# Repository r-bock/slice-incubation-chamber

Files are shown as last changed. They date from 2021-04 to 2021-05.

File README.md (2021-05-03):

# Slice incubation chamber
These files are [OpenSCAD](http://openscad.org/) files, which create a slice incubation chamber that fits into a 250 ml glass beaker. The file is the source for both, the chamber and the grid/mesh, though there are two separate STL files for them. The small holder fits the [gas dispersion tubes](https://www.fishersci.com/shop/products/pyrex-gas-dispersion-tubes-with-fritted-cylinders-2/11138B) for continued oxygenation of the imersion solution.

The chamber went through multiple iterations since 2017 and the latest is version *3 E*, 
which shows small modifications to the previous version based on specific preferences. The chambers are in constant use in a laboratory setting. 

The version *3 D* has the following design: 

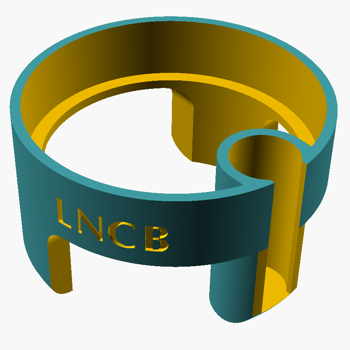
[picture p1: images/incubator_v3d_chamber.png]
incubation chamber
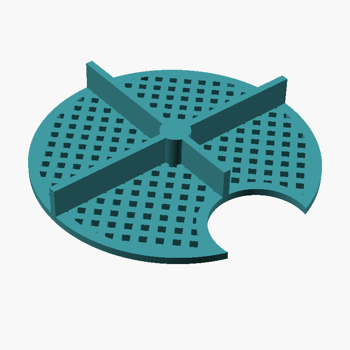
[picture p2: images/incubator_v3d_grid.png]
slice incubation grid
   

## Materials

The print material for the chamber is [PETG](https://www.acmeplastics.com/what-is-petg), which is considered food-safe. PETG worked well in the laboratory setting since 2017. *PLA* might also work, but I haven't tried it exhaustively.

The chamber needs to be submerged within a saline solution for long times, so the print material must be biological inert (i.e. not leaching any trace amounts) and create a solid surface to prevent any solution leaking into the inner structure (which, depending on the print, is often not solid but a 20-30% infill).

## Stuff

 <br />
These files are copyrighted 2021 by R. Bock and are licensed under a [Creative Commons Attribution-NonCommercial-ShareAlike 4.0 International License](http://creativecommons.org/licenses/by-nc-sa/4.0/).

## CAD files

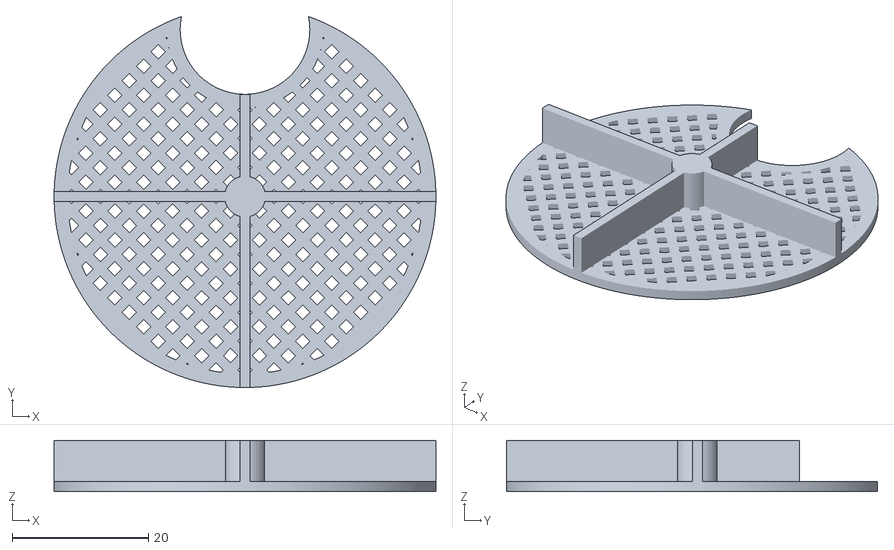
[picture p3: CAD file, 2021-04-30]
incubator_v3d_grid.stl
56.0 x 54.4 x 7.50

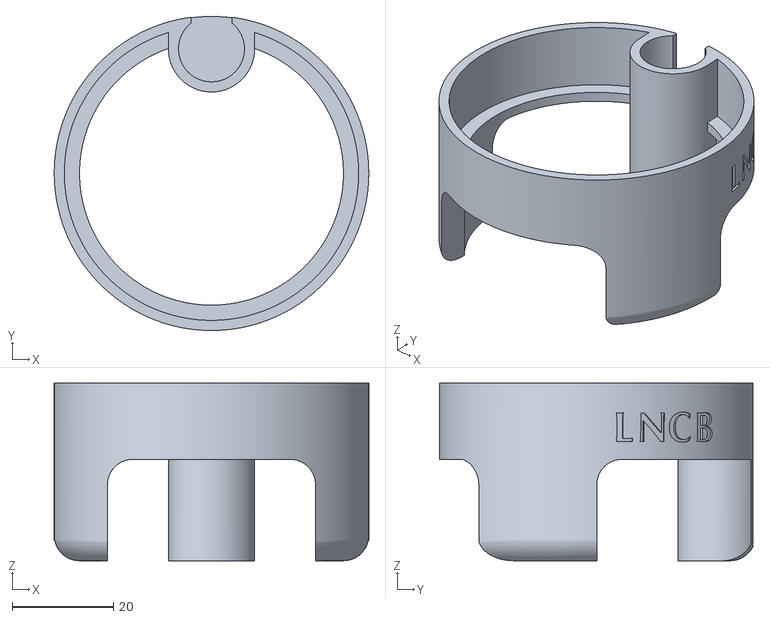
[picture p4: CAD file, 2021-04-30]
incubator_v3d_chamber.stl
62.0 x 61.9 x 35.0

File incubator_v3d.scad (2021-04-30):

// main incubation chamber
$fs=0.5;
$fa=0.5;

use <text_on.scad>;

// all measurements are given in mm!

//font = "Monaco:style=Regular";
font="Optima:style=Bold";
letterHeight=1.5;
letterSize=6;
spacing=1.1;
msg = "LNCB";
vMsg = "v3D";

beakerD = 62; 			// beaker diameter
bradius = 6.5;
bwall = 2;
bledge = 4.5;
bBottom = 3;
cwall = 2;
cheight = 15;
ledgeWidth = 3;
legheight = 20;

meshHeight = 1.5;

supportArcR = 5;

cradius = beakerD/2;
legWidth = (cradius * 2) * (1 / 2);


// main arrangement of chamber and meshes
translate([0, 0, legheight]) chamber();
// translate([2 * beakerD + beakerD/4, 0, 0]) chamber();
// translate([2 * beakerD + beakerD/4, beakerD + beakerD/8, 0]) rotate([0, 0, 180]) chamber();


// for (t = [ [-beakerD/2-8, beakerD-5, -legheight],
//           [beakerD/4+5, beakerD-5, -legheight],
//           [beakerD + 5, 0, -legheight],
//           [-(beakerD + 5), 0, -legheight], 
//           [1.3 * beakerD, beakerD-5, -legheight] ])
//     translate(t) grid(barThick, bDist, fBorder, tol, 1.5);

* grid(barThick, bDist, fBorder, tol, 1.5);

// modules
module chamber() {
	difference() {
	// chamber with bubble holder
	union() {
		// main chamber
		difference() {
			color("aqua")
				translate([0,0,-legheight]) cylinder(r=cradius,h=cheight + legheight);
			translate([0,0,2]) cylinder(r=cradius-cwall, h=cheight);
			translate([0,0,-legheight - 1]) cylinder(r=cradius-cwall-ledgeWidth, h=cheight + legheight);
			translate([0,cradius-bradius,-legheight]) cylinder(r=bradius, h=cheight + legheight + 5);

			// creating a block to crated the legs with nice rounds
			translate([0,cradius-legWidth+supportArcR,-legheight-(supportArcR/2)+0.5]) {
				minkowski() {
					rotate([0,90,0]) cylinder(r=supportArcR,h=cradius + 2, center=true);
					translate([-cradius/2,0,0]) 
						cube([cradius,legWidth-supportArcR,legheight - supportArcR + 2]);
				}
			}
	
			// separating arc
			translate([-legWidth/2,-beakerD/2+((cwall+ledgeWidth) * 3),-legWidth-1+supportArcR])
				rotate([90,0,0])
					linear_extrude(height=(cwall+ledgeWidth+5) * 2)
						minkowski() {
							square([legWidth, legheight + 2]);
							circle(r=supportArcR);
						}
			
			text_on_cylinder(msg, r=cradius, h=13, font=font, size=letterSize, extrusion_height=letterHeight, eastwest=122, spacing=spacing);
			text_on_cylinder(vMsg, r=cradius, h=13, font=font, size=letterSize, extrusion_height=letterHeight, eastwest=-120, spacing=spacing);
		}

		difference() {
			union() {
				// now for the bubble holder
				translate([0,cradius-bradius,-legheight])	{
	    				difference() {
	        				cylinder(r=bradius + bwall, h=legheight+cheight);
						translate([0,0,bBottom])
//							difference() {
								cylinder(r=bradius, h=cheight+legheight+2);
//								rotate([-10,0,0])
//									translate([-bradius-1, -bradius-1, -(bradius/2) * 0.65])
//										cube([(2 * bradius) + 2, (2 * bradius) + 2, bradius/2]);
//							}

//    		    				translate([0,0,bBottom])
//     	   					cylinder(r=bradius, h=legheight+cheight);
    					}
				}

				// bubble connector
				translate([-bradius-bwall,cradius-bradius,0]) {
					difference() {
						cube([(bradius+bwall)*2,bradius+bwall,cheight]);
						translate([bradius+bwall,0,-1])
							cylinder(r=bradius, h=cheight+2);
						translate([bradius+bwall,-beakerD/2+bradius+bwall-0.5, -1]) {
							difference() {
								cylinder(d=beakerD+5, h=cheight+2);
								cylinder(d=beakerD, h=cheight+2);	
							}
						}
					}
				}
			}

			translate([0,0,-legheight-1]) {
				linear_extrude(height=cheight+legheight+2) {
					difference() {
						offset(r=3)
							circle(r=cradius); 
						circle(r=cradius);
						
					}
				}
			}			
		}
	}

	translate([0, cradius, bBottom-bwall])
		cube([bwall * 4, bwall * 1.5, cheight+legheight + 0.95], center=true);
	
	
	// slant the legs
	scale([1,1.01,1]) {
		translate([0,-bradius-bwall/2,-legheight+supportArcR]) {
			difference() {
				translate([0,bradius+(bwall/2),-supportArcR-1])
					linear_extrude(height=supportArcR, convexity=10)
						circle(d=beakerD);

				difference() {
					translate([0,bradius+(bwall/2),0])
						rotate_extrude(convexity=10)
							translate([beakerD/2-supportArcR,0,0]) circle(r=supportArcR);

					translate([0,bradius+(bwall/2),0])
						linear_extrude(height=supportArcR, convexity=10) circle(d=beakerD);
				}

				translate([0,bradius+(bwall/2),-supportArcR-2])
					linear_extrude(height=2*supportArcR, convexity=10)
						circle(d=beakerD-(supportArcR*2));

			}
		}
	}
	}
}

gridR = cradius-cwall-0.5;
barThick = 1.5;		// thickness of the bar in mm
bDist = 1.5;			// distance between bars in mm
tol = 1;			// tolerance, i.e. how far away from the border
fBorder = 2;		// frameborder in mm


module grid(barThick, barDist, frameBorder, tolerance, height) {
	barThick = barThick < 1 ? 1 : barThick;
	barDist = barDist < 1 ? 1 : barDist;
	frameBorder = frameBorder < 1 ? 1 : frameBorder;
	tolerance = tolerance <= 0 ? 1 : tolerance;
	height = height <= 0 ? 1.5 : height;

	linear_extrude(height=height) {
		union() {
			gridInsertFrame(frameBorder, tolerance);
			gridStructure(barThick, barDist, frameBorder, tolerance);
		}
	}
	linear_extrude(height=cheight/2, convexity=10) {
		circle(r=(barThick * 2));
		translate([-barThick/2,-gridR+(tolerance/2),0])
			square([barThick,2 * (gridR - (tolerance/2) - bradius)]);
		translate([gridR-(tolerance/2),-barThick/2,0])
			rotate([0,0,90])
				square([barThick,2 * (gridR - (tolerance/2))]);
	}
}


module gridStructure(barThick, barDist, frameBorder, tolerance) {
	barThick = barThick < 1 ? 1 : barThick;
	barDist = barDist < 1 ? 1 : barDist;
	frameBorder = frameBorder < 1 ? 1 : frameBorder;
	tolerance = tolerance <= 0 ? 1 : tolerance;
	
	numBars = ceil((gridR * 2) / (barThick + barDist));
	
	difference() {
		union() { 
			rotate([0,0,45]) {
				for (n = [0:numBars]) {
					translate([(n * (barThick + barDist)) - gridR, 0, 0])
						square([barThick,2 * gridR], center=true);
				}
			}	
			rotate([0,0,-45]) {
				for (n = [0:numBars]) {
					translate([gridR - (n * (barThick + barDist)), 0, 0])
						square([barThick,2 * gridR], center=true);
				}
			}
		}
		
		difference() {
			rotate([0,0,45]) square((2*gridR) + 2 * (barThick + barDist), center=true);
			difference() {
				circle(r=(beakerD/2) - cwall-tolerance);
				translate([0, beakerD/2 - bradius, 0]) circle(r=bradius+bwall+cwall+tolerance);
				offset(r=1)
					translate([-bradius-bwall,cradius-cwall-bradius,0])
						square([(bradius+bwall)*2, bradius+bwall]);
				
			}
		}
	}
}


module gridInsertFrame(frameBorder, tolerance) {
	frameBorder = frameBorder < 1 ? 1 : frameBorder;
	tolerance = tolerance <= 0 ? 1 : tolerance;

	difference() {
		circle(r=(beakerD/2)-cwall-tolerance);
		offset(r=-2)
			circle(r=(beakerD/2)-cwall-tolerance);
		translate([0, cradius-cwall-bradius/2, 0])
			circle(r=bradius+bwall+tolerance+1);
	}
	difference() {
		offset(r=3) {
			translate([0,cradius-bradius,0])
				circle(r=bradius+bwall);
		}
		offset(r=1) {
			translate([-bradius,cradius-cwall-bradius,0])
				square([(bradius)*2, bradius+bwall]);
			translate([0,cradius-bradius,0])
				circle(r=bradius+bwall);
		}
		difference() {
			circle(r=(beakerD/2)+cwall+bwall+5);
			circle(r=(beakerD/2)-cwall-1);
		}
	}
}

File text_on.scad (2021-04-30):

/*  text on ....
   This is a rework of version 3 of write.scad to use the new OpenSCAD internal text() primitive.
   All credit to Harlan Martin (harlan@sutlog.com) for his great effort on the original.
   Great thanks to t-paul (and the OpenSCAD dev team) on adding the new text() primitive.
*/


/*
The arguments to be provided for each function are explictly in the modules.

All modules take close to all the arguments to text() [Not all features are supported in all text_on_object() modules though -- try them out warnings will be given if it is not supported]

text() params:
t
size
spacing
font
direction -- ltr, ttb, btt or rtl
language
script
halign -- left, right or center
valign -- baseline, bottom, top or center

All modules also take the additional arguments:
extrusion_height = depth of the letter, i.e. how far it sits proud
rotate
center //center the text at the location it is being written (NOT that the object is centered)

ALL faux-objects that the text is applied to have center=true
TODO: object_center=true/false (already done for cylinder)

The above arguemnts can be seen in text_extrude() as all modules call that module evetually (often multiple times).

locn_vector -- Where the faux-object has been translated to. TODO: Rename object to translate_vector?

Additional arguments for text_on_cube():

Additional arguments for text_on_cylinder():

Additional arguments for text_on_circle():

Additional arguments for text_on_sphere():


*/

// These control the default values for text_extrude(), text_on_sphere(), text_on_cube(), text_on_cylinder(), text_on_circle()
// if the arguments are not included in the call to the module.

// Defaults
// Defaults for all modules
default_t="text_on";
default_size = 4; //TODO - Can we make this 10?? To match internal size? There is an underlying value in text() -- This masks that.
default_font = "Liberation Mono";
default_spacing = 1; //Spacing between characters. There is an underlying value in text() -- This masks that. We try and match it here.
default_rotate  = 0; // text rotation (clockwise)
default_center  = true; //Text-centering
default_scale = [1,1,1];
default_extrusion_height = 2; //mm letter extrusion height

//Defaults for Cube
default_cube_face        = "front";	 // default face (top,bottom,left,right,back,front)
default_sphere_rounded   = false;	 //default for rounded letters on text_on_sphere
default_cube_updown = 0; //mm up (-down) from center on face of cube
default_cube_rightleft = 0;		 //mm right(-left) from center on face of cube

//Defaults for Sphere
default_sphere_northsouth= 0;
default_sphere_eastwest  = 0;
default_sphere_spin      = 0; //TODO:Different to rotate? or up/down. Better name?

//Defaults for Cylinder (including circle as it is on top/bottom)
default_circle_middle    = 0;      //(mm toward middle of circle)
default_circle_ccw       = false;  //write on top or bottom in a ccw direction
default_circle_eastwest  = 0;
default_cylinder_face    = "side";
default_cylinder_updown  = 0;

//Internal values - don't play with these :)
//This is much more accurate than the PI constant internal to Openscad.
internal_pi=3.1415926535897932384626433832795028841971693993751058209;
internal_pi2=internal_pi*2;

//Internal values - You might want to play with these if you are using a proportional font
internal_space_fudge = 0.9; //Fudge for working out lengths (widths) of strings

debug = true;

//---- Helper Functions ----
//String width (length from left to right or RTL) in OpenSCAD units
//NOTE: These are innacurate because we don't know the real spacing of the chars and so have to approximate
//They work for monospaced (fixed-width) fonts well
function width_of_text_char( size, spacing ) = (size * internal_space_fudge * spacing);
function width_of_text_string_num_length(length, size, spacing) = ( width_of_text_char( size, spacing ) * (length));
function width_of_text_string( t, size, spacing ) = ( width_of_text_string_num_length(len(t), size, spacing) );

function cylinder_center_adjusted_top( height, center )    = (center==true) ? height/2 : height ;
function cylinder_center_adjusted_bottom( height, center ) = (center==true) ? height/2 : 0 ;


//Angle that measures width of letters on perimeter of a circle (and sphere and cylinder)
function rotation_for_character(size, spacing, r, rotate = 0)
 = ( width_of_text_char( size, spacing ) /(internal_pi2*r))*360*(1-abs(rotate)/90);


//Rotate 1/2 width of text if centering	
//One less -- if we have a single char we are already centred..
function rotation_for_center_text_string( t, size, spacing,r,rotate,center)
	= (center) ? (width_of_text_string_num_length( len(t)-1, size, spacing )/2/(internal_pi2*r)*360) : 0 ;

//Rotate according to rotate and if centred text also 1/2 width of text
function rotation_for_center_text_string_and_rotate( t, size, spacing,r,rotate,center)
	= ((center) ? (width_of_text_string( t, size, spacing )/2/(internal_pi2*r)*360) : 1) * (1-abs(rotate)/90);


//---- Text on Object Functions ----
//Text on the top or side of a cylinder.
//Supports writing on normal and slanty cylinders
//cylinder(h,r,center)
//cylinder(h,r1,r2,center)
module text_on_cylinder(t=default_t,
                        //Object-specific                        
                        locn_vec = [0,0,0],
                        r,r1,r2,h,
                        face             = default_cylinder_face,
                        updown           = default_cylinder_updown,
                        rotate           = default_rotate,
                        eastwest         = default_circle_eastwest,
                        middle           = default_circle_middle,
                        ccw              = default_circle_ccw,
                        cylinder_center  = false, //if the cylinder object we are writing on is center==true
                        //TODO: add rounded
                        
                        //All objects
                        extrusion_height = default_extrusion_height,
                        center           = default_center,
                        //All objects -- arguments as for text()
                        font             = undef,
                        size             = default_size,
                        direction        = undef,
                        halign           = undef,
                        valign           = undef,
                        language         = undef,
                        script           = undef,
                        spacing          = default_spacing
){
//    echo (str("text_on_cylinder:There are " ,len(t) ," letters in t" , t));
//    echo (str("text_on_cylinder:","h" , h));
//    echo (str("text_on_cylinder:","r=" , r));
//    echo (str("text_on_cylinder:","r1=" , r1));
//    echo (str("text_on_cylinder:","r2=" , r2));

    if((halign!=undef) || (halign!=undef))
    {
        echo (str("text_on_cylinder:","WARNING " , "halign and valign are NOT supported."));
    }

	rtl_sign = (direction=="rtl") ? -1 : 1;
	if ((face=="top")||(face=="bottom") ){
		//Work on a circle
		locn_offset_vec = (face=="top" ) ? [0,0,cylinder_center_adjusted_top(h,cylinder_center)] : [0,0,cylinder_center_adjusted_bottom(h,cylinder_center)] ;
		rotation_angle = (face=="top" ) ? 0 : 180 ;
		int_radius =  (r==undef) ? ((face=="top" ) ? r2 : r1 ) : r;  //Use the top/bottom radius for slanty-cylinders
			rotate(rotation_angle,[1,0,0])
			text_on_circle(t,locn_vec+locn_offset_vec,r=int_radius-size,
				font=font,size=size,
				spacing=spacing,direction=direction,language=language,script=script,halign=halign,valign=valign,
				extrusion_height=extrusion_height,
				rotate=rotate,
				eastwest=eastwest,middle=middle,ccw=ccw);
	}else{
		if((middle!=undef) && (middle!=default_circle_middle))
		{
			//TODO: Which others?
			//TODO: Which side things aren't supported on the circle
			echo (str("text_on_cylinder:","WARNING " , "middle NOT supported for the SIDE of a cylinder."));
		}
		//Work on the side
		locn_offset_vec =  (cylinder_center==true) ? [0,0,0] : [0,0,h/2]; 
		rotate(-rtl_sign * rotation_for_center_text_string_and_rotate(t, size, spacing,r,rotate,center), [0,0,1])
		translate(locn_vec+locn_offset_vec)
		__internal_text_on_cylinder_side(t,locn_vec,r=r,h=h,r1=r1,r2=r2,
			cylinder_center=cylinder_center,
			center=center,
			font=font,size=size,
			spacing=spacing,direction=direction,language=language,script=script,halign=halign,valign=valign,
			extrusion_height=extrusion_height,
			rotate=rotate,face=face,updown=updown,
			eastwest=eastwest);
	}
}

//circle(r)
module text_on_circle(t=default_t,
                      //Object-specific
                      locn_vec = [0,0,0],
                      r,
                      eastwest = default_circle_eastwest,
                      middle = default_circle_middle,
                      ccw = default_circle_ccw,
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

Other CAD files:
incubator_v3e.scad
incubator_v3f.scad

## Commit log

2021-04-30 update readme with images of chamber and license
2021-04-30 initial commit of the .scad files for the 3D model
    [incubator_v3d.scad, incubator_v3e.scad]
2021-04-30 library file for the chambers to display text on the side
    [text_on.scad]
2021-04-30 added the stl files for the 3D printer for v3D
    [incubator_v3d_chamber.stl, incubator_v3d_grid.stl]
2021-04-30 update the STL files with a netfabb checked version
    [incubator_v3d_chamber.stl, incubator_v3d_grid.stl]
2021-05-03 changed hole size for grid to 2 mm after first test print
    [incubator_v3e.scad]
2021-05-03 added version 3f which reduces the holder opening by 1 mm to give the dispersion tube a bit more hold
    [incubator_v3f.scad]

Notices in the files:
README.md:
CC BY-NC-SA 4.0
